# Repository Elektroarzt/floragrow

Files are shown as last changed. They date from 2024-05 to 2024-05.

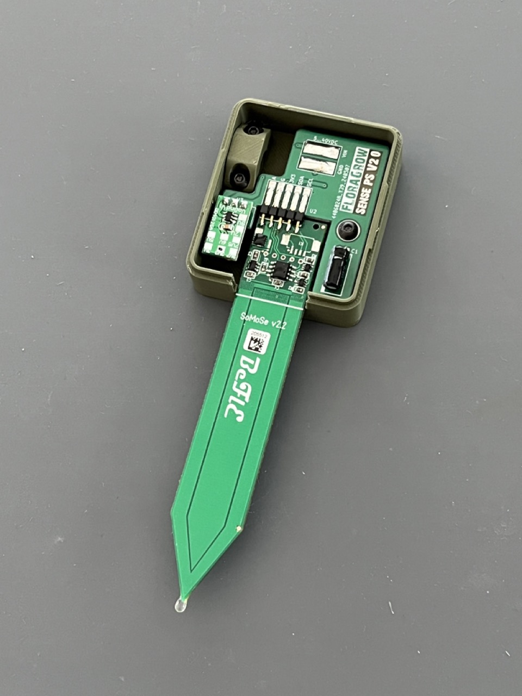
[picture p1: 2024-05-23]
Sense PS/assets/FloraGrow Sense PS overview.jpeg

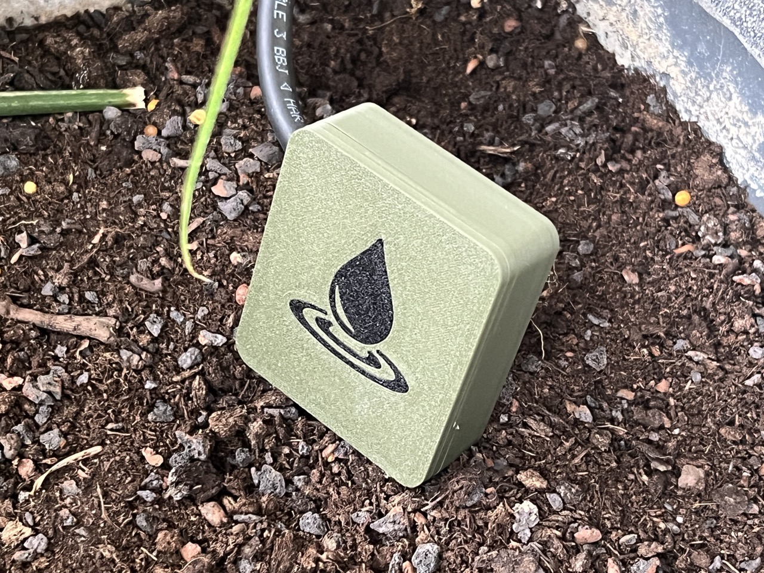
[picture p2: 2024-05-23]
Sense PS/assets/FloraGrow Sense PS in soil.jpeg

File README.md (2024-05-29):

# FloraGrow 

### Overview
This project revolves around the topic of smart irrigation in smart homes. First release is a power supplied soil moisture sensor (Sense PS). It connects via MQTT to an IoT software such as Home Assistant, ioBroker, Node-RED or similar. Later, there will likely be a variant that is powered by a battery and a valve controller with flow meters to complete the irrigation system.





### Features of the Sense PS
- Measurement of soil moisture and device temperature
- WiFi connection to an MQTT broker
- ESP32-C3 Super Mini DevBoard
- wide range power supply input 5...40V DC
- 3D printed housing
- strain relief
- epoxy resin encapsulated electronics to meet outdoor requirements
- usage of standard components

### Schematic
The schematic is quiet simple, only a few devices are put together.
 


### Partslist
You can buy the components at the following sources:
 Component                     | Name                             |Source
 :-                            |:-                                |:-
 ESP32 Development Board       | ESP32 C3 Super Mini              | Ali Express
 Soil Moisture Sensor          | SoMoSe                           | Amazon Germany
 Buck converter                | DD4012SA (3.3V Version)          | Ali Express
 Soil Moisture Sensor          | SoMoSe                           | Amazon Germany
 Electrolytic Capacitor        | 220uF /10V radial                | Reichelt, Amazon, etc.
 Power cable                   | H05RN-F 2x1                      | Amazon, some hardware stores
 Screws                        | M3 x 6mm                         | hardware store
 Housing components            | see housing 3D models folder     | self printed

### PCB
The PCB has two layers with planes for 3.3V on top and GND on the bottom side. It is populated from both sides to achieve a compact form factor. The power cord leads are directly soldered to SMD pads on the PCB.

FloraGrow Sense PS PCB top
FloraGrow Sense PS PCB bottom

### Firmware
The ESP32 of the Sense PS can be programmed with the firmware of the manufacturer of the sensor [available here](https://github.com/BeFlE/SoMoSe). The firmware facilitates the following MQTT topics:

**Published topics**

 Topic                          | Values                  | Notes
 :----------------------------- |:------------------------|:--------------------------------------------------
 somose_name/1/Humidity         | number (0...255)        | raw value of the sensor
 somose_name/1/Humidity-Average | number (0...255)        | smoothed, average value of the sensor
 somose_name/1/Name             | string                  | name of the sensor
 somose_name/1/Temperature      | number                  | temperature of the sensor in degree celsius

For details on the MQTT topics see website of the sensor manufacturer. Be sure to have the ESP32 programmed before potting ;)
After programming, the device is capable for OTA updates via its web interface.

### ESPhome
For direct integration into Home Assistant, ESPhome configuration files also can be downloaded from the sensor [manufacturer site](https://github.com/BeFlE/SoMoSe).

### Mechanics
All components are soldered to the PCB and mounted into the housing. The whole circuit is potted with 2 components resin to ensure outdoor capability.
If someone is interested in a complete device including all parts (PCBA, ESP32, housing, etc.) you can contact me under elektroarzt@digital-filestore.de.

https://github.com/Elektroarzt/floragrow/assets/61664171/9023889c-925e-4a48-a43b-feb629170dae

## Credits
The Sense Board utilizes the excellent SoMoSe (Soil Moisture Sensor) developed by BeFIE you can find under
https://github.com/BeFlE/SoMoSe and is sold on Amazon Germany

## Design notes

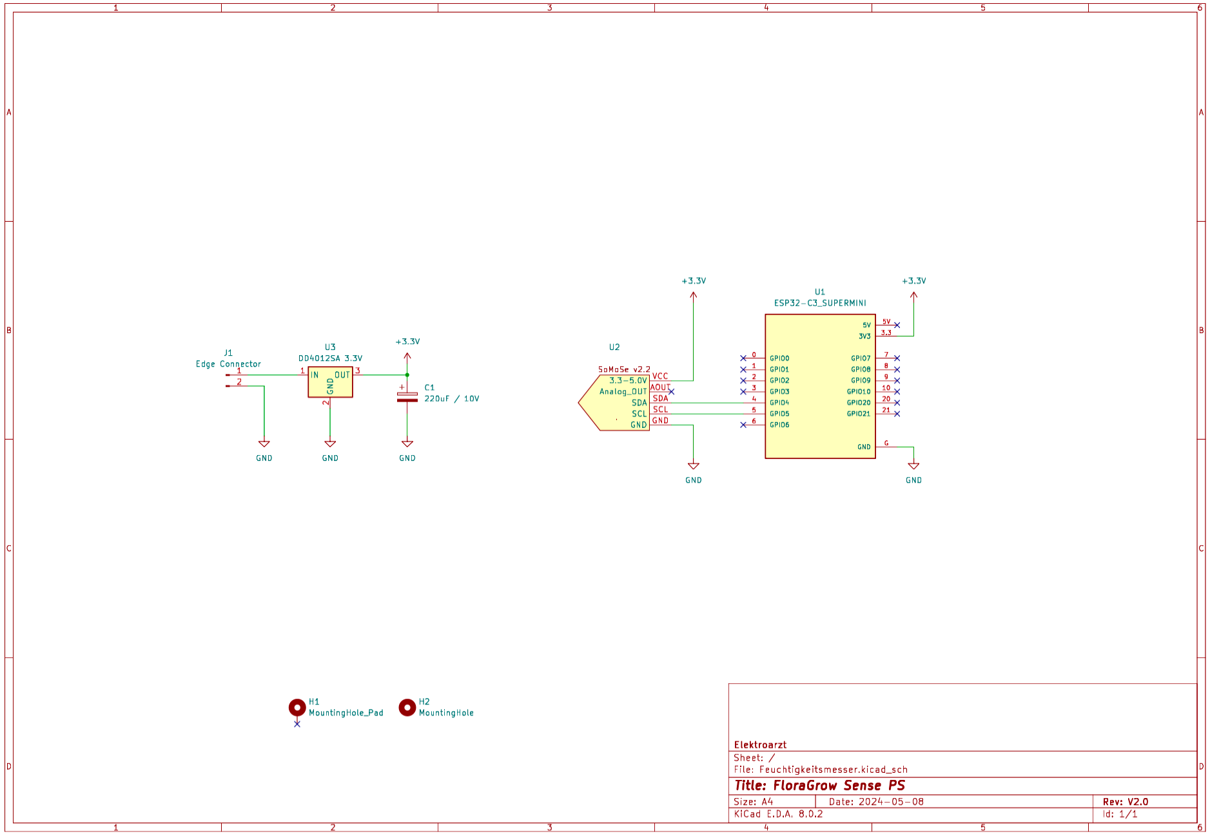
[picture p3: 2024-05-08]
Sense PS/assets/FloraGrow Sense PS V2.0 schematic.png

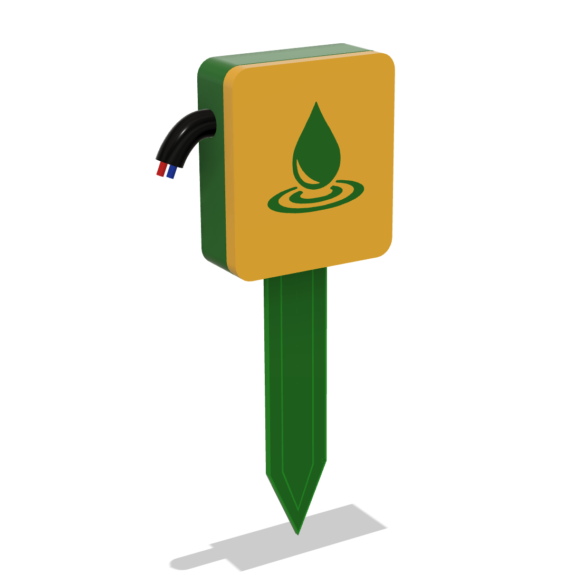
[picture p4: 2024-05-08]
Sense PS/assets/FloraGrow Sense PS front.png

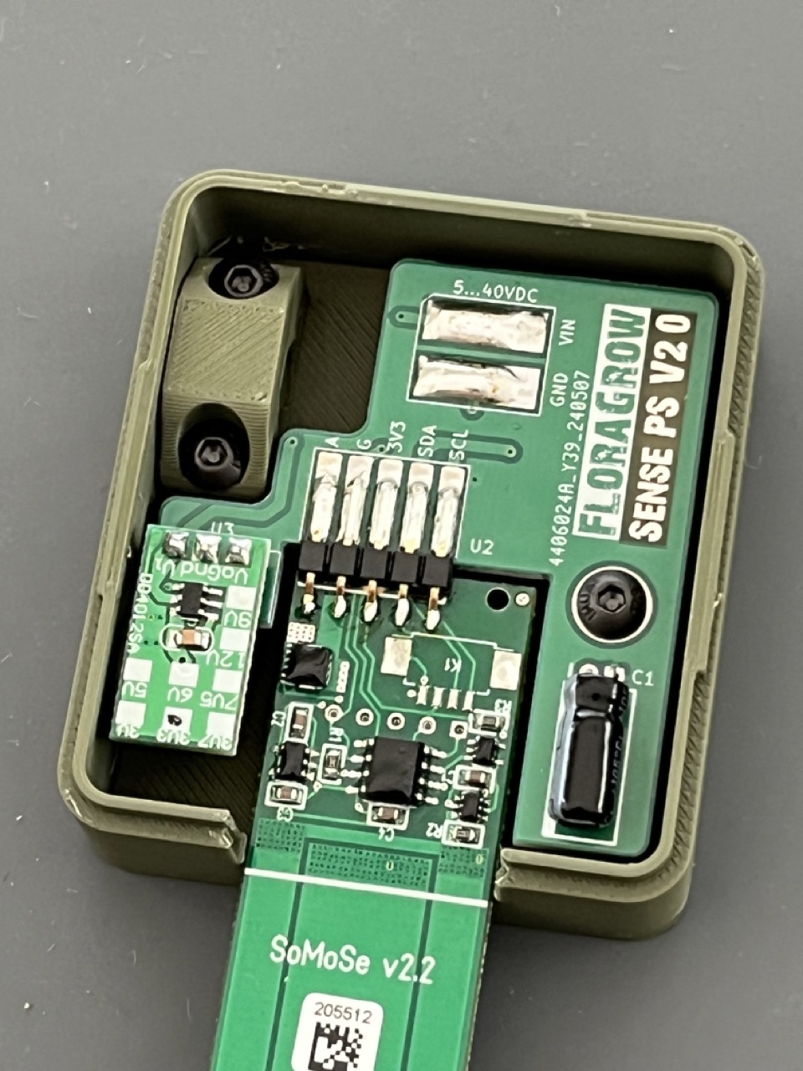
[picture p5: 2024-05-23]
Sense PS/assets/FloraGrow Sense PS detail.jpeg

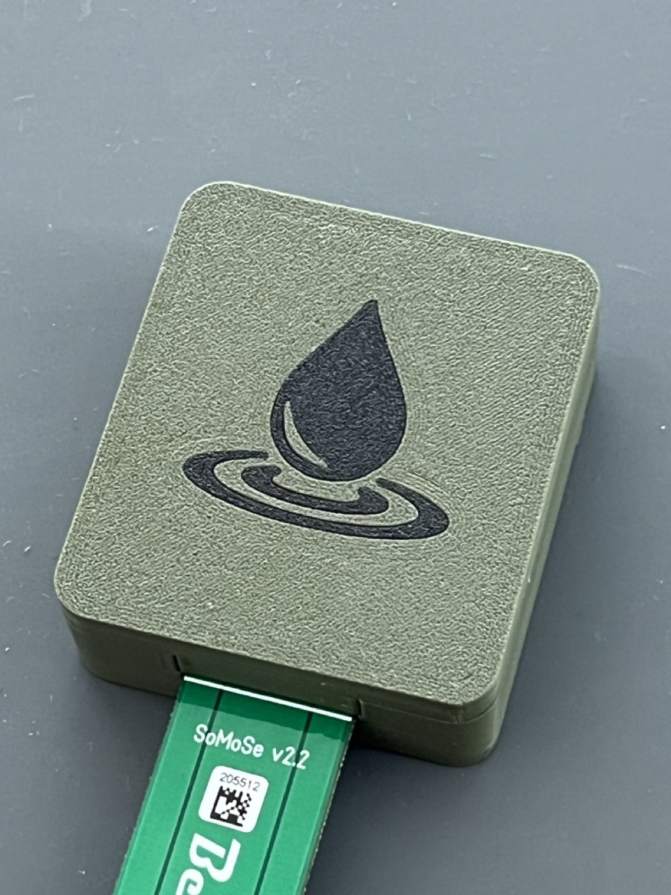
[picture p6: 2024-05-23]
Sense PS/assets/FloraGrow Sense PS covered.jpeg

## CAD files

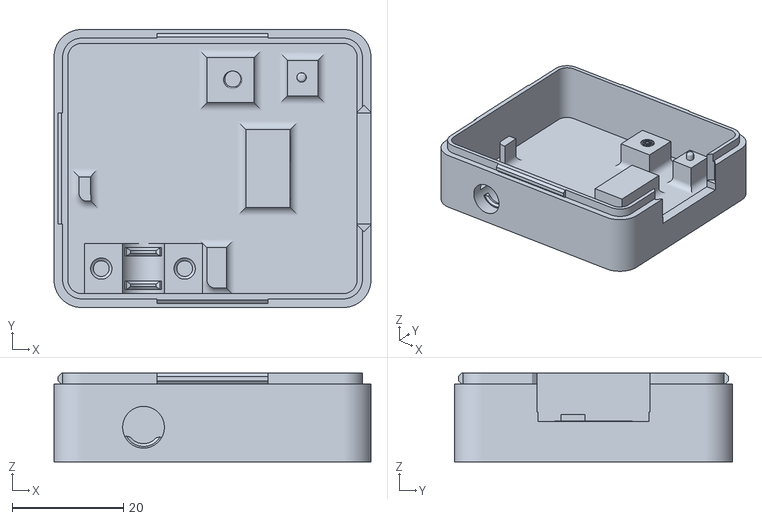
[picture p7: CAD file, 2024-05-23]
Sense PS/housing 3D models/housing V1.1.stl
57.0 x 50.0 x 16.0

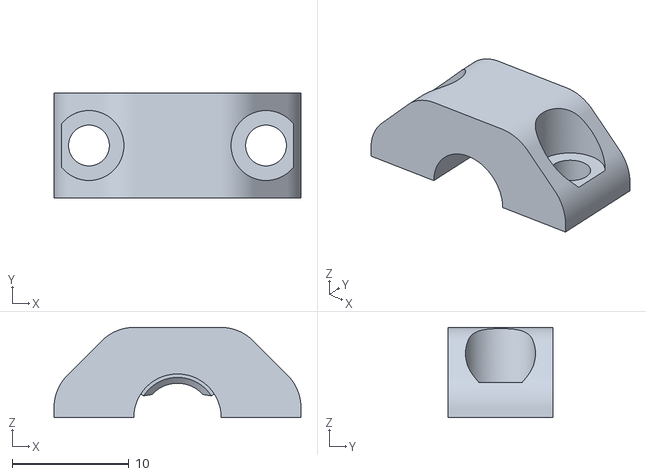
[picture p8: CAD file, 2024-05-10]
Sense PS/housing 3D models/cable clamp V1.0.stl
21.2 x 9.00 x 7.75

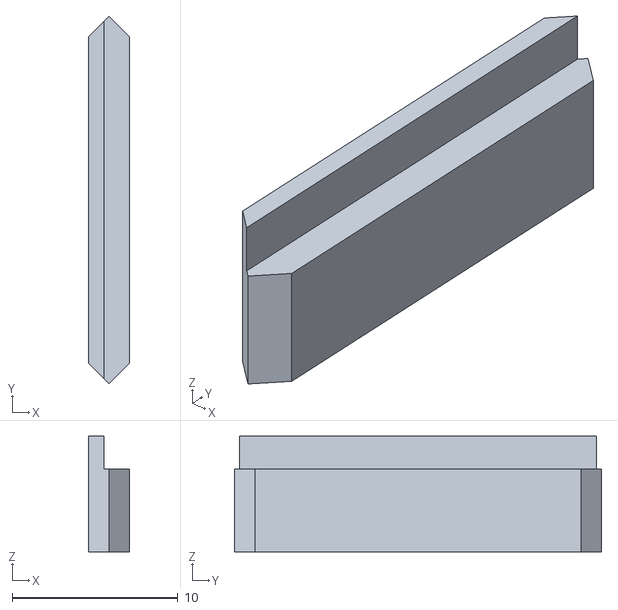
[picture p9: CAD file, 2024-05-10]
Sense PS/housing 3D models/fit component V1.0.stl
2.50 x 22.2 x 7.00

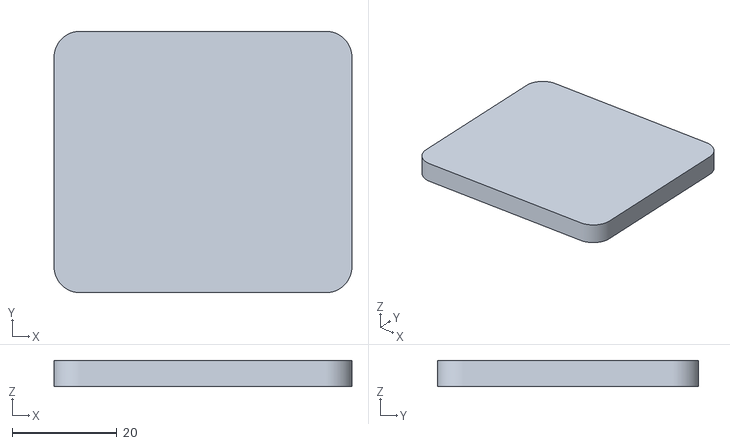
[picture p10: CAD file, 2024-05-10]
Sense PS/housing 3D models/cover V1.0.stl
57.0 x 50.0 x 5.00

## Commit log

2024-05-08 Create Sense PS mounting.mp4
2024-05-08 Added schematic
2024-05-08 Added schematic in png
2024-05-10 Added housing 3D models
    [cable clamp V1.0.stl, cover V1.0.stl, fit component V1.0.stl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]
2024-05-10 Create FloraGrow_Sense_PS_V2.0 gerber.zip
2024-05-10 renamed directory
    [cable clamp V1.0.stl, cover V1.0.stl, fit component V1.0.stl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]
2024-05-10 Create FloraGrow Sense PS PCB.png
2024-05-10 Added PCB pictures
2024-05-23 Updated housing 3D model, added pictures
    - housing now has rounded corners for more stability of PCB mounting pillars
    [housing V1.0.stl, housing V1.1.stl]
2024-05-23 Update README.md
    - Added pictures of assembled device
